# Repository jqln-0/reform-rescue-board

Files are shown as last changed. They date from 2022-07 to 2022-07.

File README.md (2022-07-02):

This is a breakout board for an MNT Reform's SOM! It's designed to make it
easier to rescue a bad bootloader flash, or work on the initial bring-up of new
SOMs.

Most of what it breaks out is already available on the Reform motherboard,
however USB1 is exposed as a micro usb port so that it's easy to use
manufacturer tools like `uuu` that rely on USB OTG functionality.

Here is what the PCB looks like in KiCad:

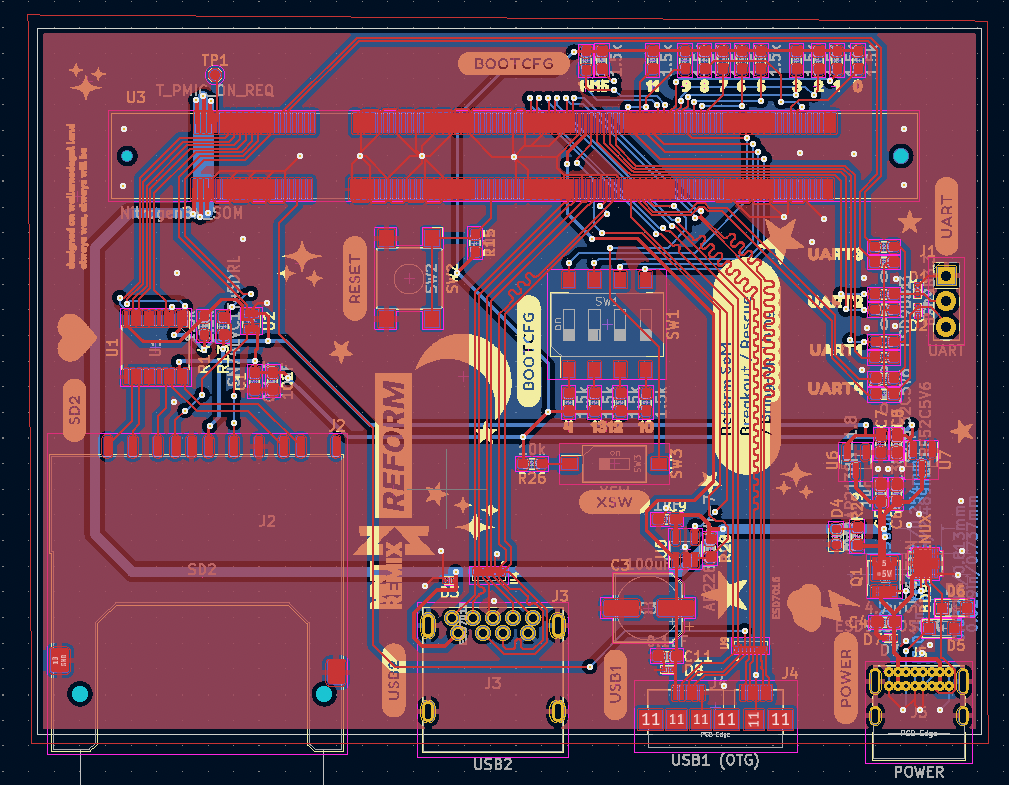
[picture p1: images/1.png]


Here is what the PCB looks like in real life:

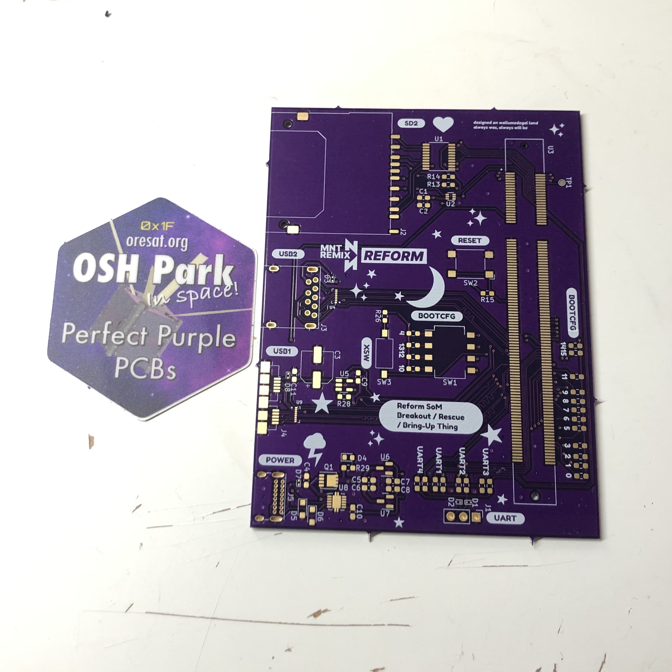
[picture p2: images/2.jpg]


Here is what an assembled board that's in-use looks like:

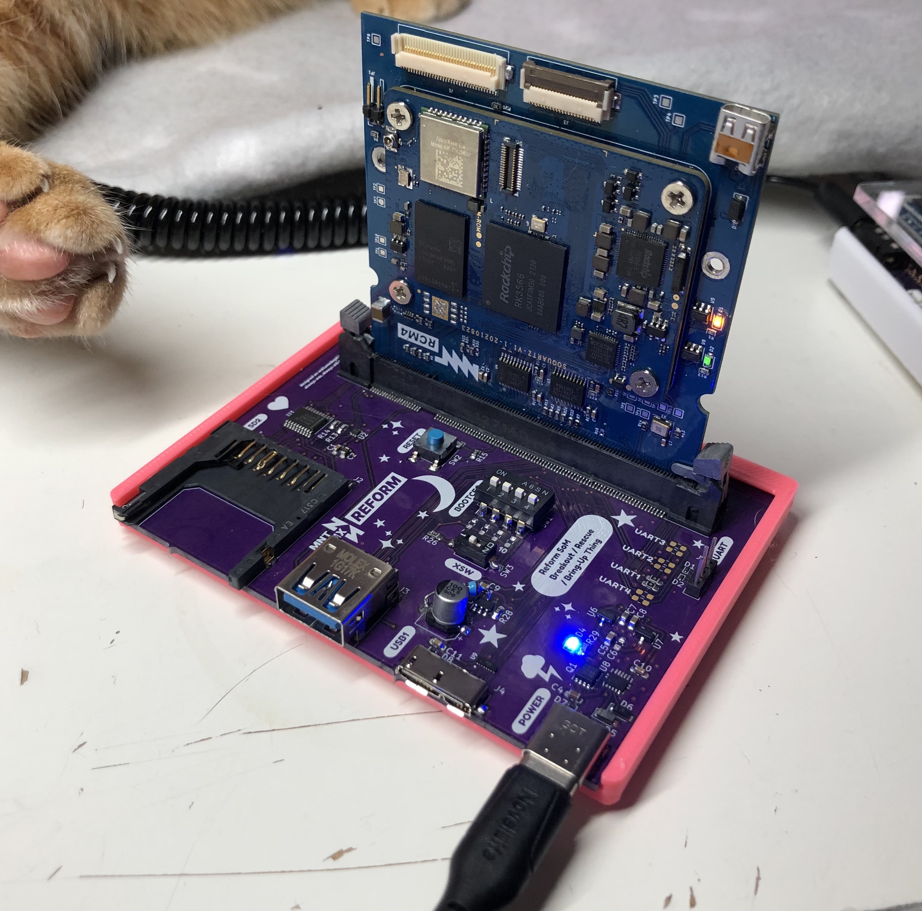
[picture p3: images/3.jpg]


(please excuse my bodges; I initially used one wrong part number + one wrong
footprint.)

Note the last picture includes the little STL in `enclosure/`. It's not very
good, but whatever. It'll do.

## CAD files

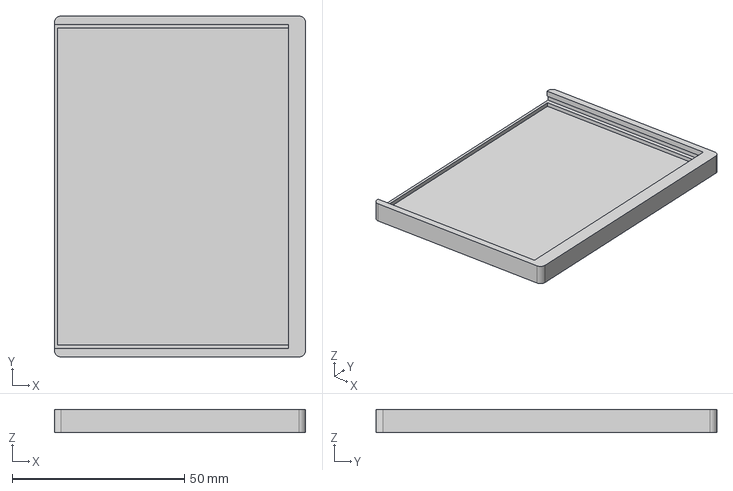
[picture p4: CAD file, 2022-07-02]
enclosure/reform_rescue_enclosureish.step
73.0 x 99.0 x 6.80 mm

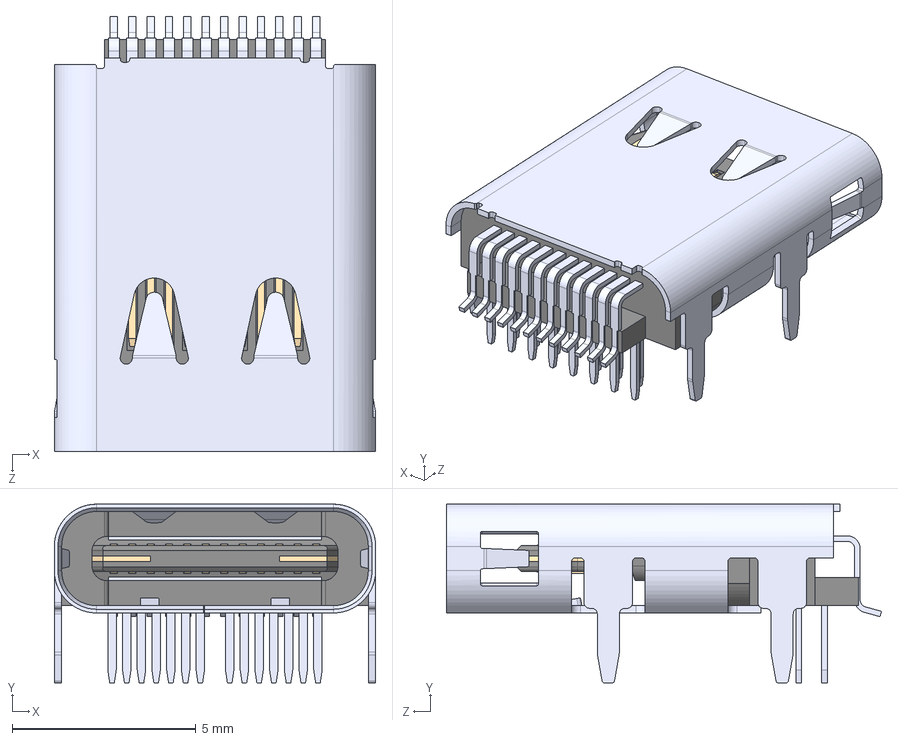
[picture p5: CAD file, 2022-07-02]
footprints/SS-52400-003--3DModel-STEP-56544.STEP
8.74 x 4.86 x 11.8 mm

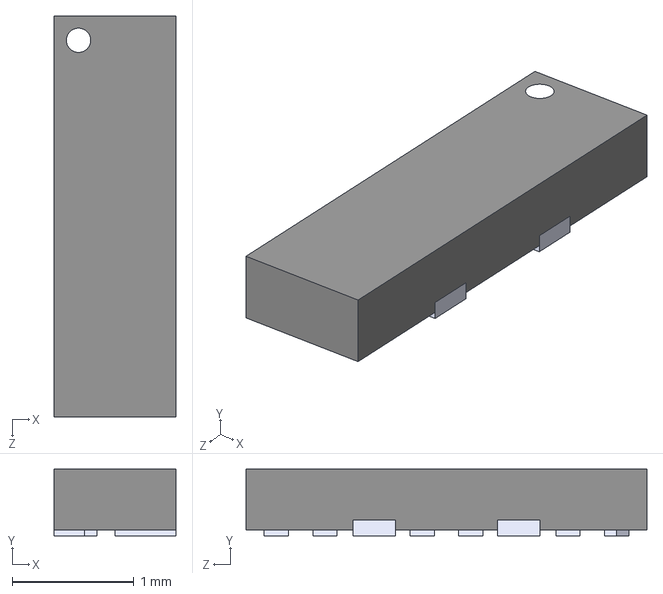
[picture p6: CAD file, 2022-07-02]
footprints/ESD7016MUTAG.step
1.00 x 0.55 x 3.30 mm

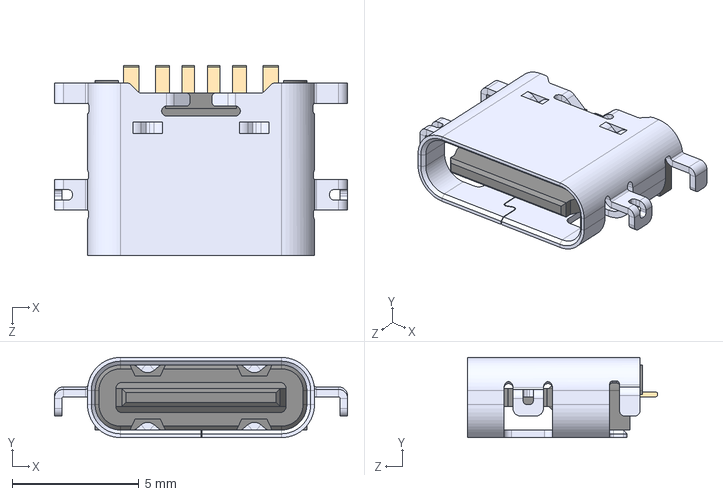
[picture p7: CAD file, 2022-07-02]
footprints/USB4515-GF-A--3DModel-STEP-269445.STEP
11.5 x 3.16 x 7.50 mm

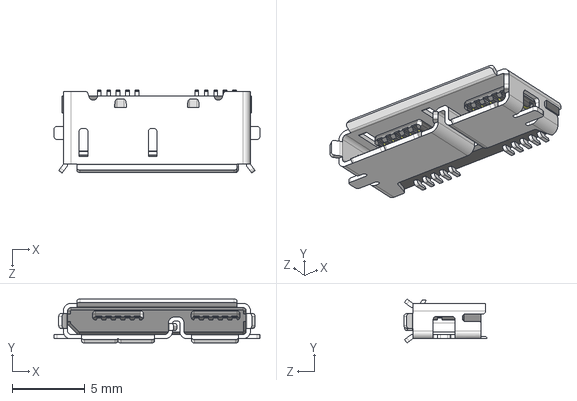
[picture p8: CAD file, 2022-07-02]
footprints/CUI_DEVICES_UJ3-MIABH-1-SMT.step
14.1 x 3.02 x 5.71 mm

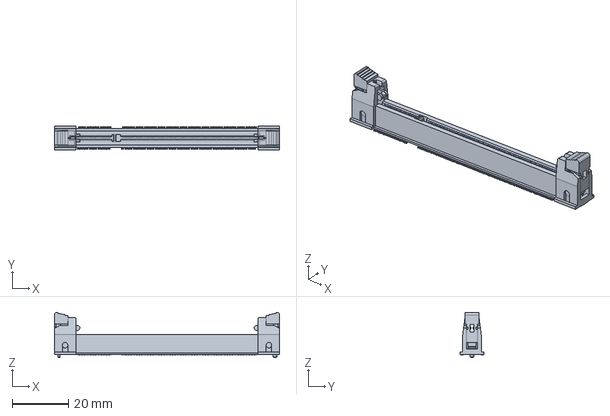
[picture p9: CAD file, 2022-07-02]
footprints/2040910-1.step
79.8 x 8.40 x 16.0 mm

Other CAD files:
enclosure/reform_rescue_enclosureish.stl

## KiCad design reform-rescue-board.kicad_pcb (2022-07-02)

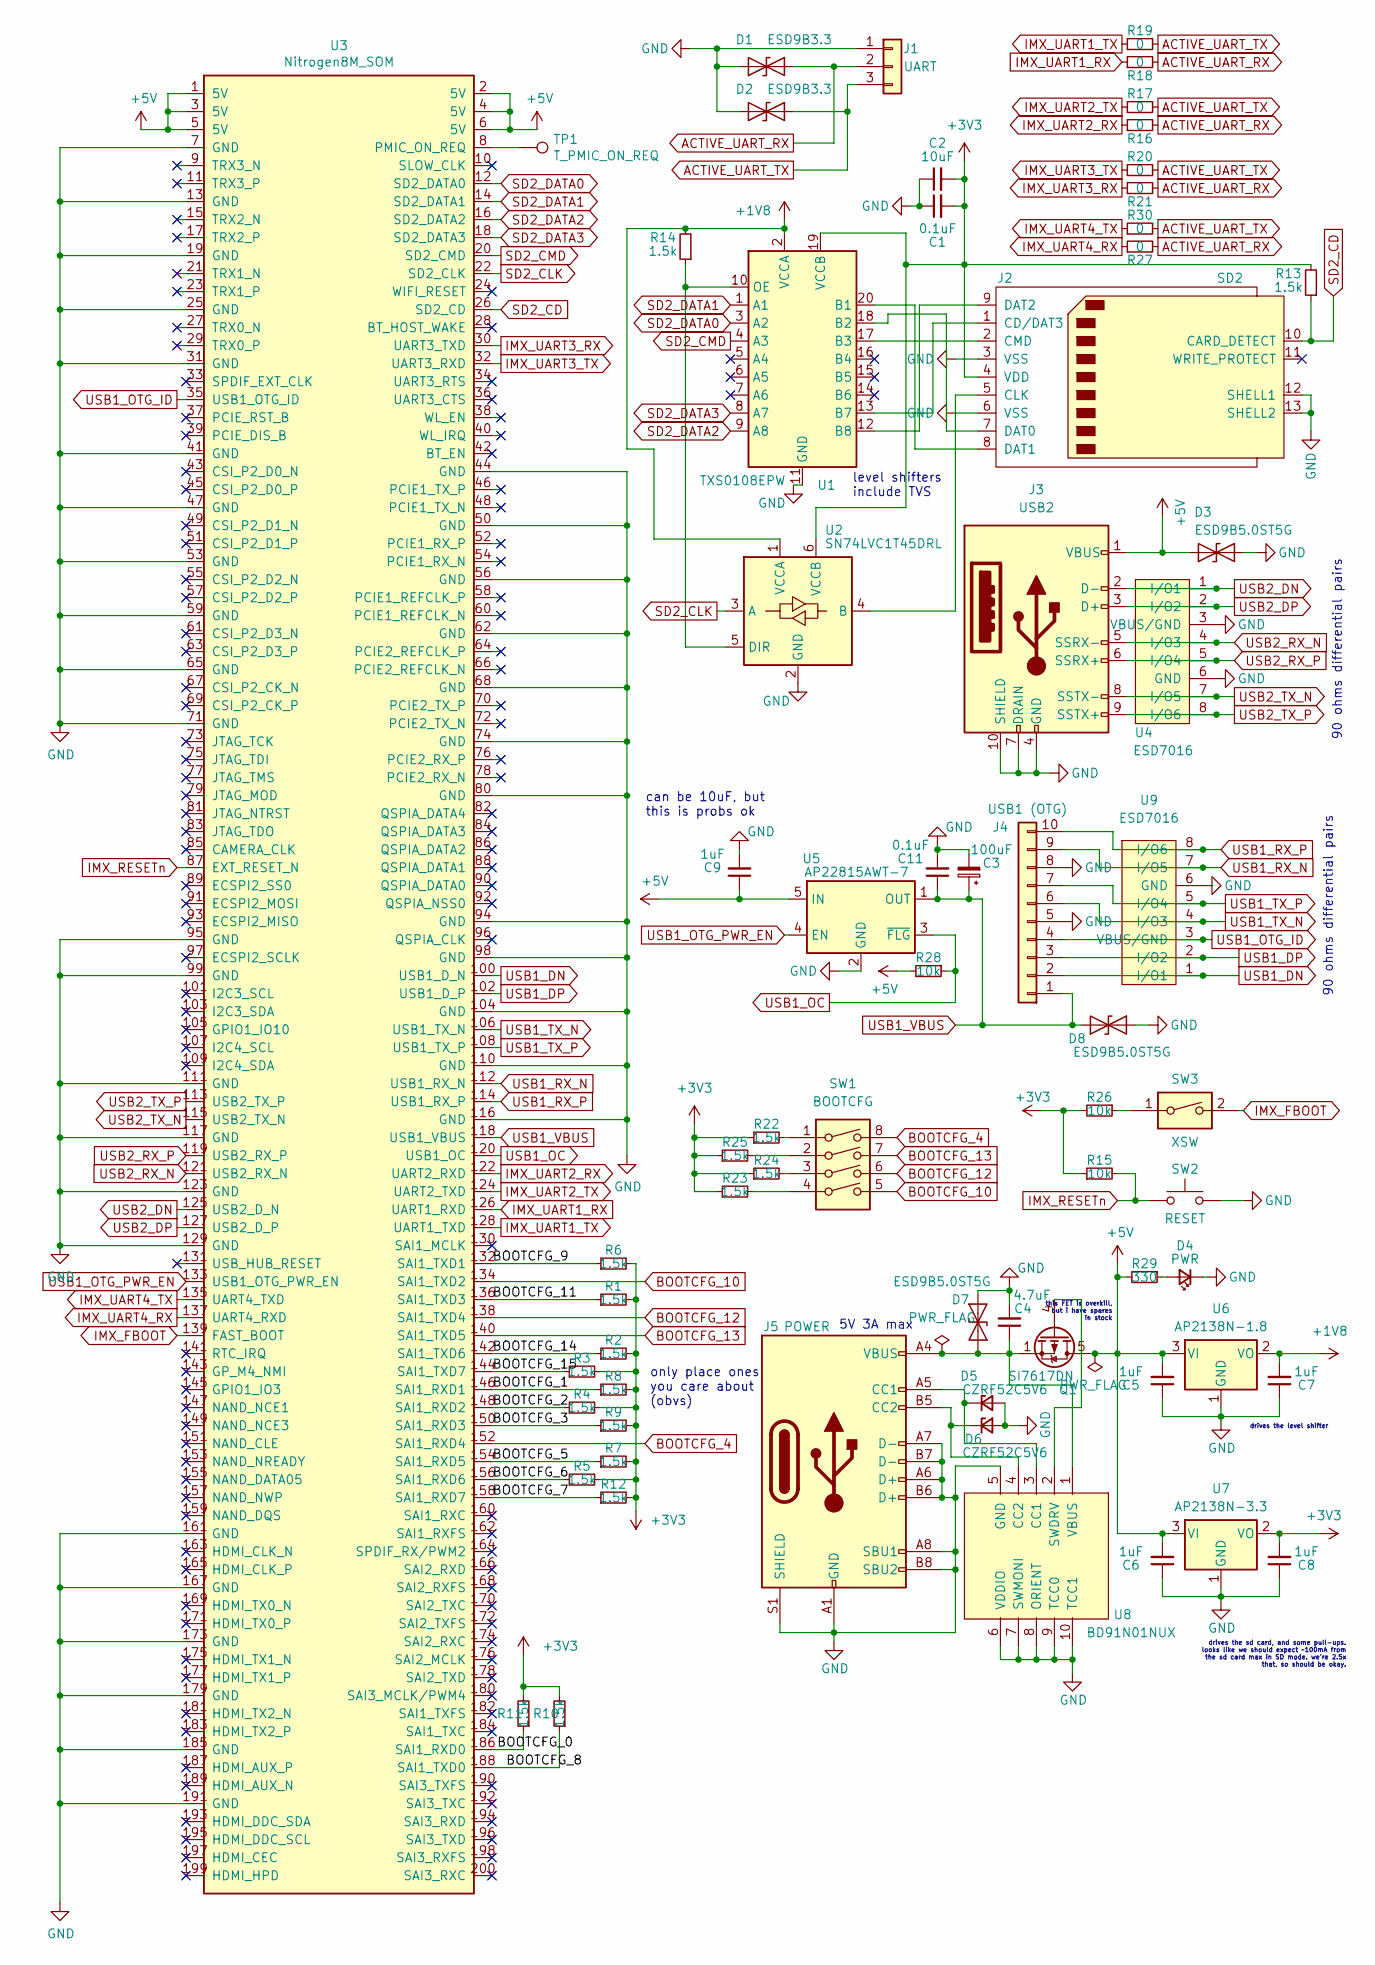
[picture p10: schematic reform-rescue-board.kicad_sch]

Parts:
C1, C11: 0.1uF; C_0603_1608Metric_Pad1.08x0.95mm_HandSolder
C2: 10uF; C_0603_1608Metric_Pad1.08x0.95mm_HandSolder
C3: 100uF; CP_Elec_6.3x5.8
C4: 4.7uF; C_0603_1608Metric_Pad1.08x0.95mm_HandSolder
C5, C6, C7, C8, C9: 1uF; C_0603_1608Metric_Pad1.08x0.95mm_HandSolder
D1, D2: ESD9B3.3; D_SOD-923
D3, D7, D8: ESD9B5.0ST5G; D_SOD-923
D4: PWR; D_0603_1608Metric
D5, D6: CZRF52C5V6; D_SOD-323_HandSoldering
J1: UART; PinHeader_1x03_P2.54mm_Vertical
J2: SD2; SD_Kyocera_145638109511859+
J3: USB2; USB3_A_Molex_48393-001
J4: USB1 (OTG); USB3_Micro-B_Connfly_DS1104-01
J5: POWER; USB_C_Receptacle_HRO_TYPE-C-31-M-12
Q1: SI7617DN; Vishay_PowerPAK_1212-8_Single
R1, R2, R3, R4, R5, R6, R7, R8, R9, R10, R11, R12, R13, R14, R22, R23, R24, R25: 1.5k; R_0603_1608Metric_Pad0.98x0.95mm_HandSolder
R15, R26, R28: 10k; R_0603_1608Metric_Pad0.98x0.95mm_HandSolder
R16, R17, R18, R19, R20, R21, R27, R30: 0; R_0603_1608Metric_Pad0.98x0.95mm_HandSolder
R29: 330; R_0603_1608Metric_Pad0.98x0.95mm_HandSolder
SW1: BOOTCFG; SW_DIP_SPSTx04_Slide_Omron_A6S-410x_W8.9mm_P2.54mm
SW2: RESET; SW_SPST_Omron_B3FS-100xP
SW3: XSW; SW_DIP_SPSTx01_Slide_Omron_A6S-110x_W8.9mm_P2.54mm
TP1: T_PMIC_ON_REQ; TestPoint_Pad_D1.0mm
U1: TXS0108EPW; TSSOP-20_4.4x6.5mm_P0.65mm
U2: SN74LVC1T45DRL; SOT-563
U3: Nitrogen8M_SOM; TE_2040910-1
U4, U9: ESD7016; TVS_ESD7016MUTAG
U5: AP22815AWT-7; SOT-23-5
U6: AP2138N-1.8; SOT-23
U7: AP2138N-3.3; SOT-23
U8: BD91N01NUX; VSON-10-1EP_3x3mm_P0.5mm_EP1.65x2.4mm

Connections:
+1V8: C7.2, R14.2, U1.2 (VCCA), U2.1 (VCCA), U6.2 (VO)
+3V3: C1.2, C2.2, C8.2, J2.4 (VDD), R1.2, R2.2, R3.2, R4.2, R5.2, R6.2, R7.2, R8.2, R9.2, R10.2, R11.2, R12.2, R13.2, R15.1, R22.1, R23.1, R24.1, R25.1, R26.2, U1.19 (VCCB), U2.6 (VCCB), U7.2 (VO)
+5V: C5.2, C6.2, C9.1, D3.1 (A1), J3.1 (VBUS), Q1.5 (D), R28.2, R29.2, U3.1 (5V), U3.2 (5V), U3.3 (5V), U3.4 (5V), U3.5 (5V), U3.6 (5V), U5.5 (IN), U6.3 (VI), U7.3 (VI)
/BOOTCFG_0: R11.1, U3.186 (SAI1_RXD0)
/BOOTCFG_1: R8.1, U3.146 (SAI1_RXD1)
/BOOTCFG_2: R4.1, U3.148 (SAI1_RXD2)
/BOOTCFG_3: R9.1, U3.150 (SAI1_RXD3)
/BOOTCFG_5: R7.1, U3.154 (SAI1_RXD5)
/BOOTCFG_6: R5.1, U3.156 (SAI1_RXD6)
/BOOTCFG_7: R12.1, U3.158 (SAI1_RXD7)
/BOOTCFG_8: R10.1, U3.188 (SAI1_TXD0)
/BOOTCFG_9: R6.1, U3.132 (SAI1_TXD1)
/BOOTCFG_11: R1.1, U3.136 (SAI1_TXD3)
/BOOTCFG_14: R2.1, U3.142 (SAI1_TXD6)
/BOOTCFG_15: R3.1, U3.144 (SAI1_TXD7)
ACTIVE_UART_RX: D1.1 (A1), J1.2, R16.2, R18.2, R21.2, R27.2
ACTIVE_UART_TX: D2.1 (A1), J1.3, R17.2, R19.2, R20.2, R30.2
BOOTCFG_4: SW1.8, U3.152 (SAI1_RXD4)
BOOTCFG_10: SW1.5, U3.134 (SAI1_TXD2)
BOOTCFG_12: SW1.6, U3.138 (SAI1_TXD4)
BOOTCFG_13: SW1.7, U3.140 (SAI1_TXD5)
IMX_FBOOT: SW3.2, U3.139 (FAST_BOOT)
IMX_RESETn: R15.2, SW2.1, U3.87 (EXT_RESET_N)
IMX_UART1_RX: R18.1, U3.126 (UART1_RXD)
IMX_UART1_TX: R19.1, U3.128 (UART1_TXD)
IMX_UART2_RX: R16.1, U3.122 (UART2_RXD)
IMX_UART2_TX: R17.1, U3.124 (UART2_TXD)
IMX_UART3_RX: R21.1, U3.30 (UART3_TXD)
IMX_UART3_TX: R20.1, U3.32 (UART3_RXD)
IMX_UART4_RX: R27.1, U3.137 (UART4_RXD)
IMX_UART4_TX: R30.1, U3.135 (UART4_TXD)
unnamed: C4.1, D7.1 (A1), J5.A4 (VBUS), J5.A9 (VBUS), J5.B4 (VBUS), J5.B9 (VBUS), Q1.1 (S), Q1.2 (S), Q1.3 (S), U8.1 (VBUS)
unnamed: D4.2 (A), R29.1
unnamed: D5.1 (K), J5.A5 (CC1), U8.3 (CC1)
unnamed: D6.1 (K), J5.B5 (CC2), U8.4 (CC2)
unnamed: J2.1 (CD/DAT3), U1.13 (B7)
unnamed: J2.2 (CMD), U1.17 (B3)
unnamed: J2.7 (DAT0), U1.18 (B2)
unnamed: J2.8 (DAT1), U1.20 (B1)
unnamed: J2.9 (DAT2), U1.12 (B8)
unnamed: Q1.4 (G), U8.2 (SWDRV)
unnamed: R14.1, U1.10 (OE), U2.5 (DIR)
unnamed: R22.2, SW1.1
unnamed: R23.2, SW1.4
unnamed: R24.2, SW1.3
unnamed: R25.2, SW1.2
unnamed: R26.1, SW3.1
unnamed: TP1.1, U3.8 (PMIC_ON_REQ)
SD2_CD: J2.10 (CARD_DETECT), R13.1, U3.26 (SD2_CD)
SD2_CLK: U2.3 (A), U3.22 (SD2_CLK)
SD2_CMD: U1.4 (A3), U3.20 (SD2_CMD)
SD2_DATA0: U1.3 (A2), U3.12 (SD2_DATA0)
SD2_DATA1: U1.1 (A1), U3.14 (SD2_DATA1)
SD2_DATA2: U1.9 (A8), U3.16 (SD2_DATA2)
SD2_DATA3: U1.8 (A7), U3.18 (SD2_DATA3)
USB1_DN: J4.2, U3.100 (USB1_D_N), U9.1 (I/O1)
USB1_DP: J4.3, U3.102 (USB1_D_P), U9.2 (I/O2)
USB1_OC: R28.1, U3.120 (USB1_OC), U5.3 (~FLG)
USB1_OTG_ID: J4.4, U3.35 (USB1_OTG_ID), U9.3 (VBUS/GND)
USB1_OTG_PWR_EN: U3.133 (USB1_OTG_PWR_EN), U5.4 (EN)
USB1_RX_N: J4.9, U3.112 (USB1_RX_N), U9.7 (I/O5)
USB1_RX_P: J4.10, U3.114 (USB1_RX_P), U9.8 (I/O6)
USB1_TX_N: J4.6, U3.106 (USB1_TX_N), U9.4 (I/O3)
USB1_TX_P: J4.7, U3.108 (USB1_TX_P), U9.5 (I/O4)
USB1_VBUS: C3.1, C11.1, D8.2 (A2), J4.1, U3.118 (USB1_VBUS), U5.1 (OUT)
USB2_DN: J3.2 (D-), U3.125 (USB2_D_N), U4.1 (I/O1)
USB2_DP: J3.3 (D+), U3.127 (USB2_D_P), U4.2 (I/O2)
USB2_RX_N: J3.5 (SSRX-), U3.121 (USB2_RX_N), U4.4 (I/O3)
USB2_RX_P: J3.6 (SSRX+), U3.119 (USB2_RX_P), U4.5 (I/O4)
USB2_TX_N: J3.8 (SSTX-), U3.115 (USB2_TX_N), U4.7 (I/O5)
USB2_TX_P: J3.9 (SSTX+), U3.113 (USB2_TX_P), U4.8 (I/O6)

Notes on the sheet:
only place ones you care about (obvs)
level shifters include TVS
drives the sd card, and some pull-ups. looks like we should expect ~100mA from the sd card max in SD mode. we're 2.5x that, so should be okay.
90 ohms differential pairs
5V 3A max
this FET is overkill, but i have spares in stock
drives the level shifter
can be 10uF, but this is probs ok

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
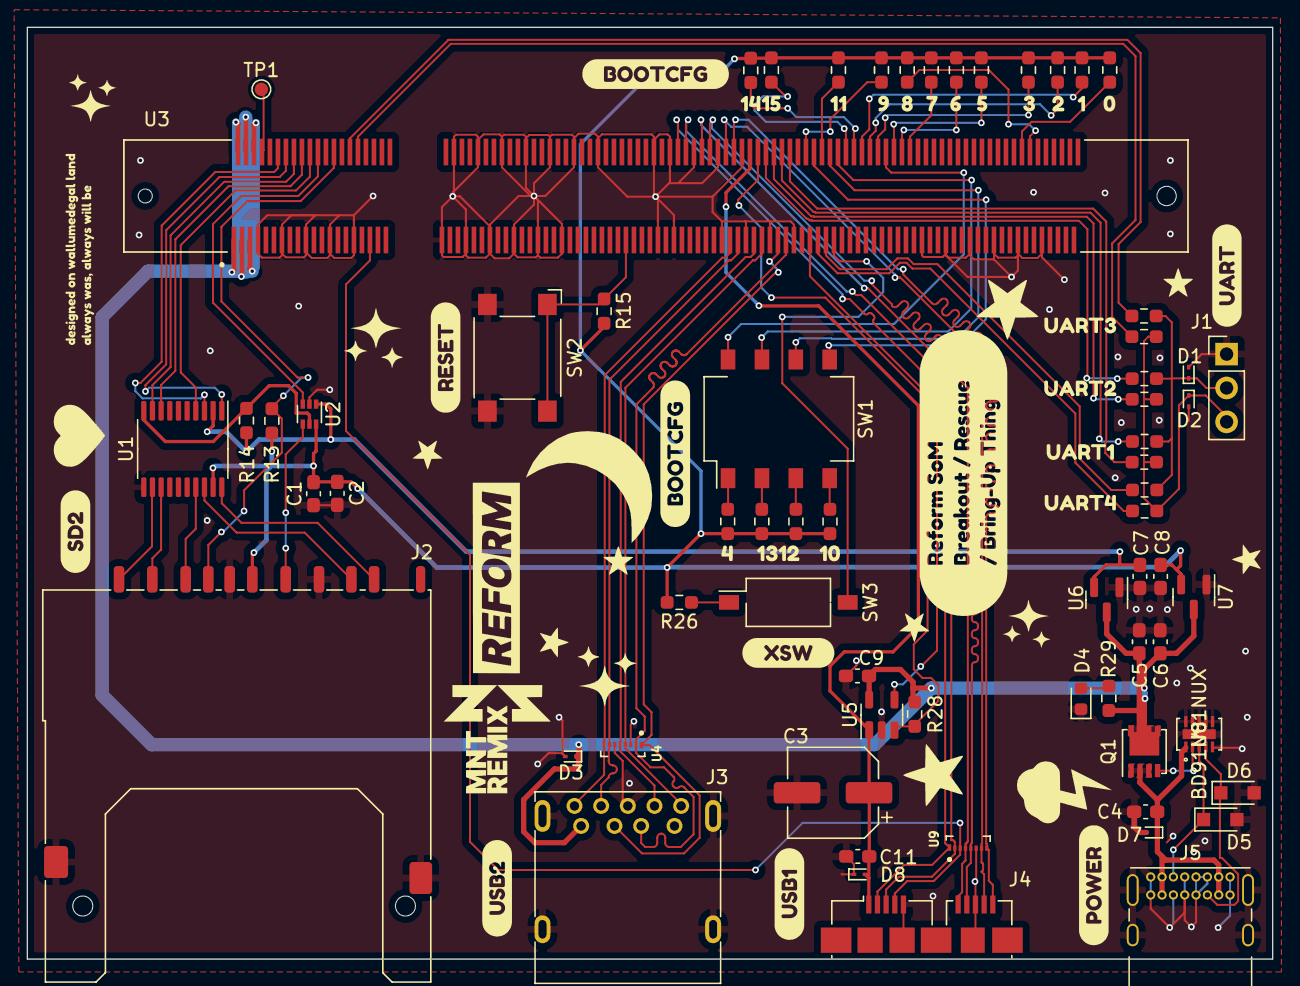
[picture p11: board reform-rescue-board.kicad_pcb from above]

Board: 2 copper layers, 93.4 x 69.9 mm, 103 parts (0 on the bottom side), 73 nets.

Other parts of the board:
G: LOGO; star_small
G#2, G#3, G#4, G#5, G#6: LOGO; star_small
kibuzzard-62A7FD84, kibuzzard-62A7FD84#2: G***; kibuzzard-62A7FD84
kibuzzard-62A7FDA4: G***; kibuzzard-62A7FDA4
kibuzzard-62A7FDB1: G***; kibuzzard-62A7FDB1
kibuzzard-62A7FDB8: G***; kibuzzard-62A7FDB8
kibuzzard-62A7FDC1: G***; kibuzzard-62A7FDC1
kibuzzard-62A7FDCC: G***; kibuzzard-62A7FDCC
kibuzzard-62A7FDD2: G***; kibuzzard-62A7FDD2
kibuzzard-62A7FDDB: G***; kibuzzard-62A7FDDB
kibuzzard-62A7FDE3: G***; kibuzzard-62A7FDE3
kibuzzard-62A7FDE9: G***; kibuzzard-62A7FDE9
kibuzzard-62A7FDEF: G***; kibuzzard-62A7FDEF
kibuzzard-62A7FE5E: G***; kibuzzard-62A7FE5E
kibuzzard-62A7FE70: G***; kibuzzard-62A7FE70
kibuzzard-62A7FE79: G***; kibuzzard-62A7FE79
kibuzzard-62A7FE86: G***; kibuzzard-62A7FE86
kibuzzard-62A7FEC5: G***; kibuzzard-62A7FEC5
kibuzzard-62A7FF2B: G***; kibuzzard-62A7FF2B
kibuzzard-62A7FF03: G***; kibuzzard-62A7FF03
kibuzzard-62A7FF4E: G***; kibuzzard-62A7FF4E
kibuzzard-62A7FF9A: G***; kibuzzard-62A7FF9A
kibuzzard-62A7FF26: G***; kibuzzard-62A7FF26
kibuzzard-62A7FF56: G***; kibuzzard-62A7FF56
kibuzzard-62A7FFAE: G***; kibuzzard-62A7FFAE
kibuzzard-62A7FFC0: G***; kibuzzard-62A7FFC0
kibuzzard-62A7FFCB: G***; kibuzzard-62A7FFCB
kibuzzard-62A7FFD3: G***; kibuzzard-62A7FFD3
kibuzzard-62A7FFD7: G***; kibuzzard-62A7FFD7
kibuzzard-62A82825: G***; kibuzzard-62A82825
kibuzzard-62A82953: G***; kibuzzard-62A82953

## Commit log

2022-07-02 Initial commit, probably missing footprints
    [2040910-1.step, CUI_DEVICES_UJ3-MIABH-1-SMT.step, ESD7016MUTAG.step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]
2022-07-02 Add my little enclosure thing
    [reform_rescue_enclosureish.step, reform_rescue_enclosureish.stl]

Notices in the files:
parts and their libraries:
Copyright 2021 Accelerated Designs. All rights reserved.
